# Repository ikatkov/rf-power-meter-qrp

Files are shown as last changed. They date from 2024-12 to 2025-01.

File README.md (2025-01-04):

# RF Power Meter QRP

This microcontroller-based RF power meter is tailored for Ham QRP, capable of measuring up to 6W. It offers power readings in two formats:

1. Milliwatts (mW) – displayed as a 4-digit value without decimals.
1. Decibel-milliwatts (dBm) – shown with one decimal place. Since the display lacks a dot, the reading appears as a 3-digit number (e.g., "123" represents 12.3 dBm).
1. Accuracy 0.4% @ 6W (+-25mW), 5% @ 10mW (+-0.5mW)

## Features

- Up to 6W RF power meter, assumes sin wave
- Peak power hold mode
- Compensated frequency resonse, less that 1.03 SWR 2-50MHz
- Power measurements in dBm and Watts on 4-digit LED display
- Support for multiple Ham frequency bands (3.7-50MHz)
- Calibrated and uses polynomial curve fitting for accurate measurements. Manually set frequency band in settings.
- Battery voltage monitoring and auto power-off after 5 minutes of inactivity. Press any button to reset.
- Vent holes on plastic enclosure have filters made of surgical mask fiber (anti dust for field operation)

## 2MHz - 50MHz
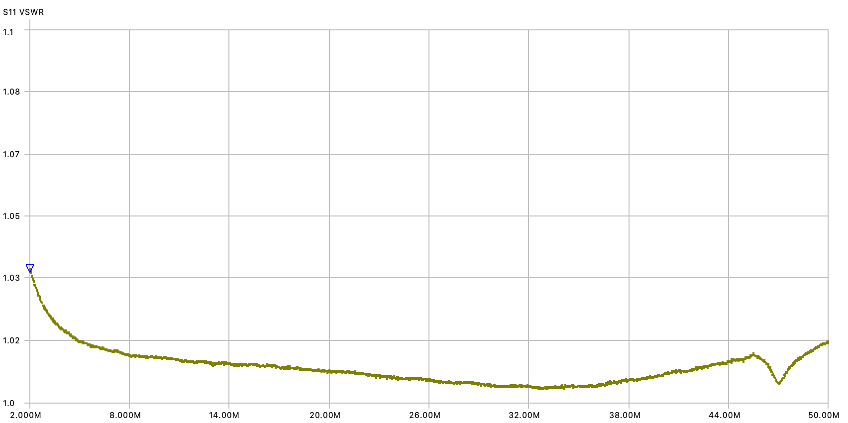
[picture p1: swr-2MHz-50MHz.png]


## 2MHz - 175MHz
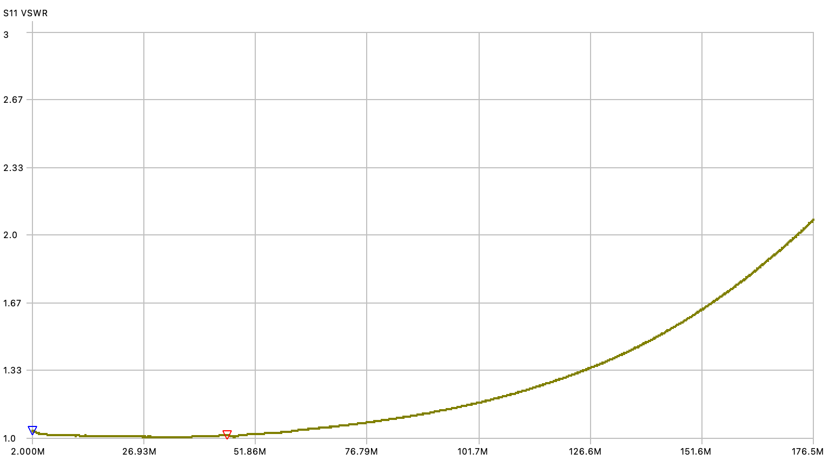
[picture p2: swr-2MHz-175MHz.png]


## Hardware

Schematic - [PDF](schematic.pdf)

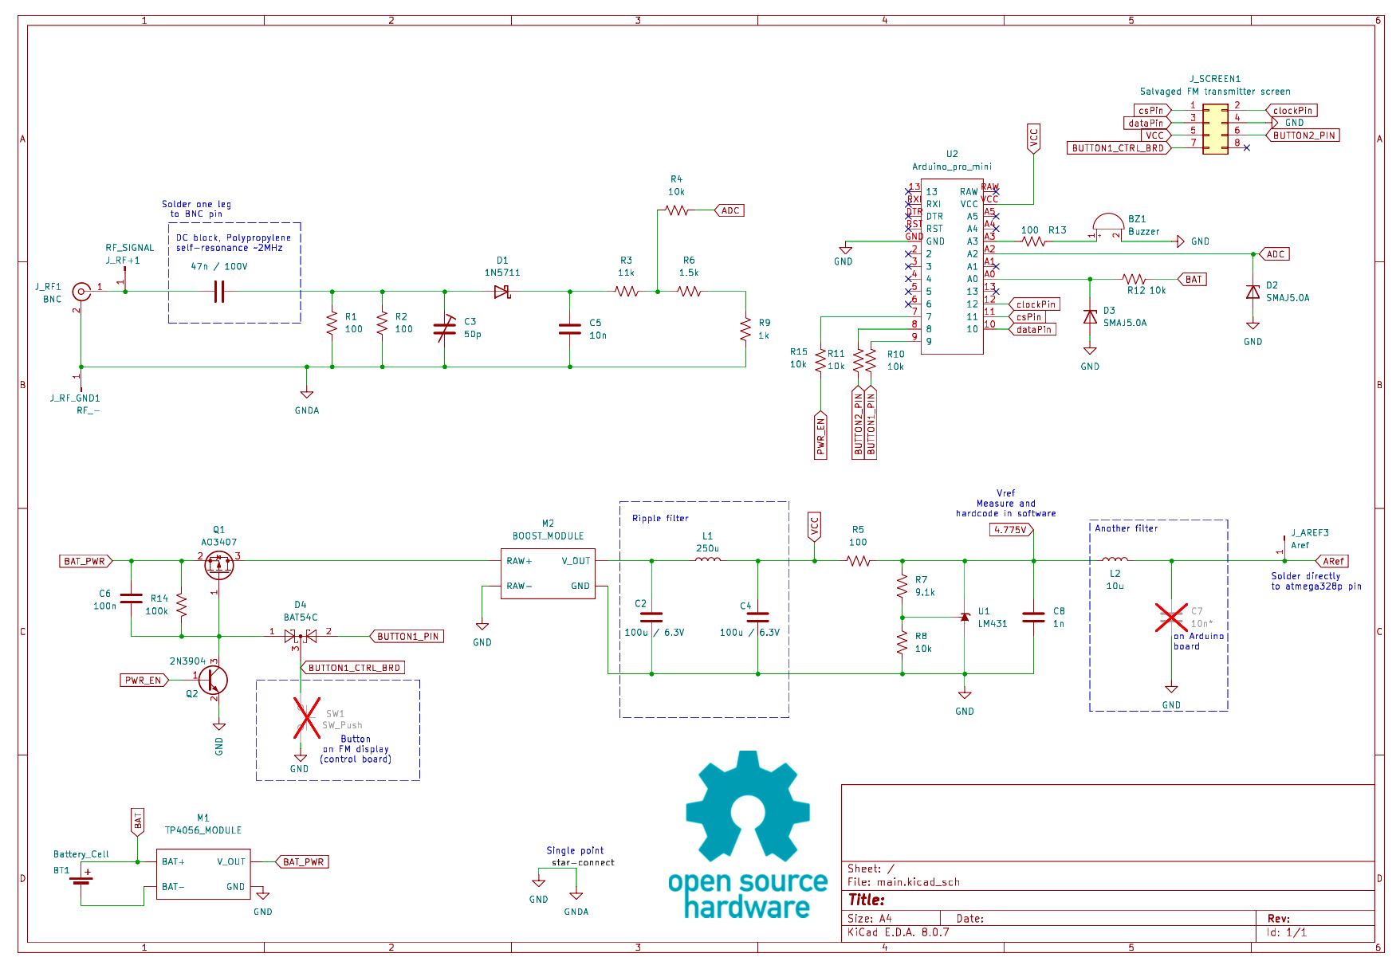
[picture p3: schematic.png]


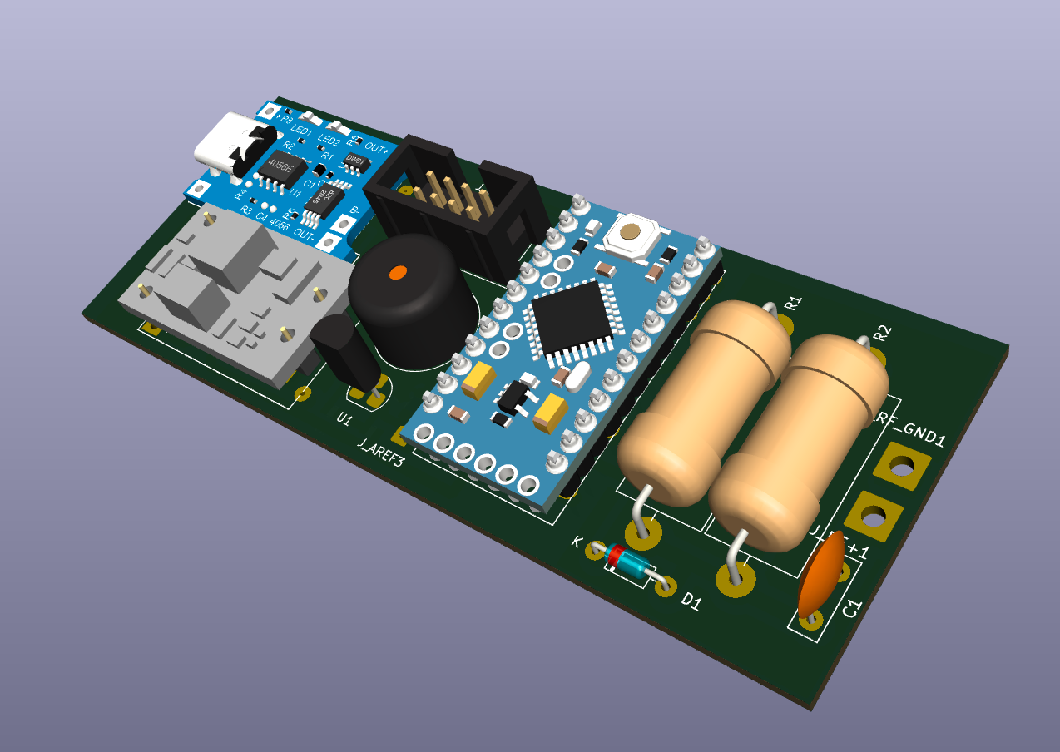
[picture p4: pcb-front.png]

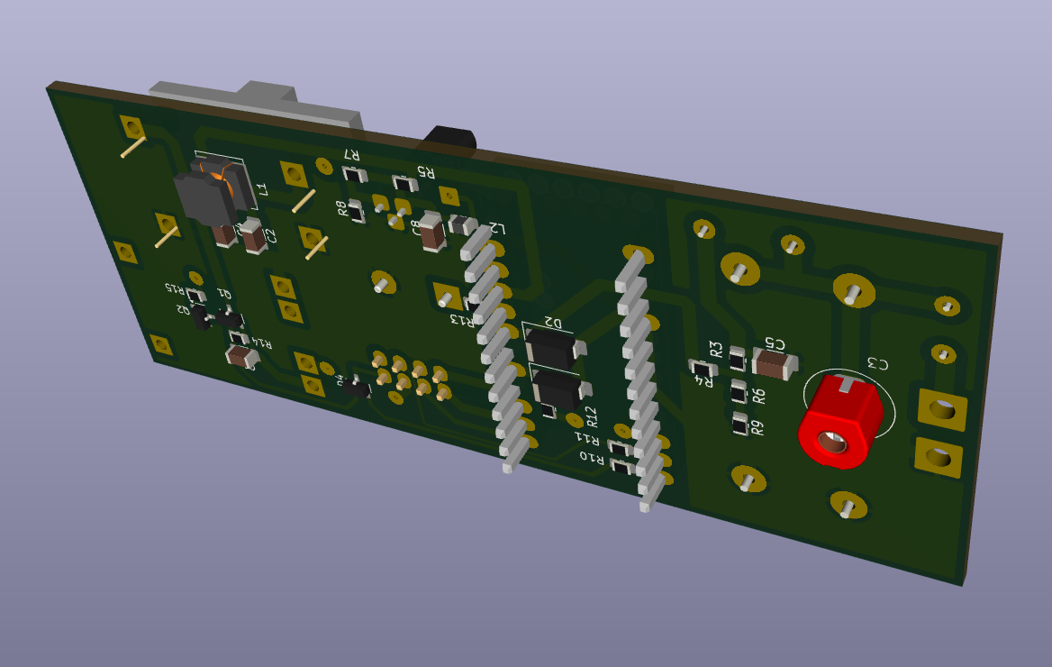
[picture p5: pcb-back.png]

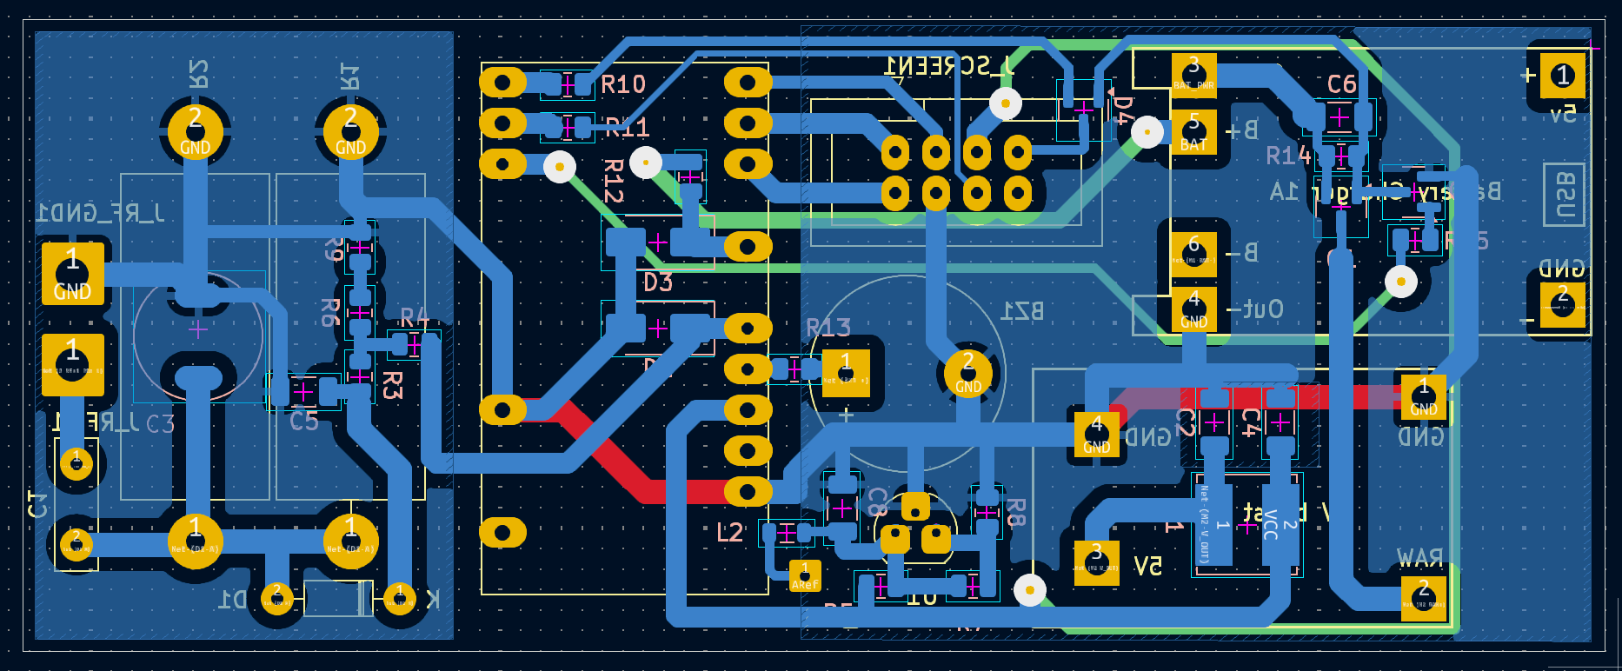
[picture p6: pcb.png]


- Arduino-compatible microcontroller
- 4-digit+MHz symbol LED display (salavged from a car FM transmitter)
- RF didode detector circuit
- Power latch circuit for MCU driven turn off
- Buzzer for audio feedback
- External precision voltage reference 

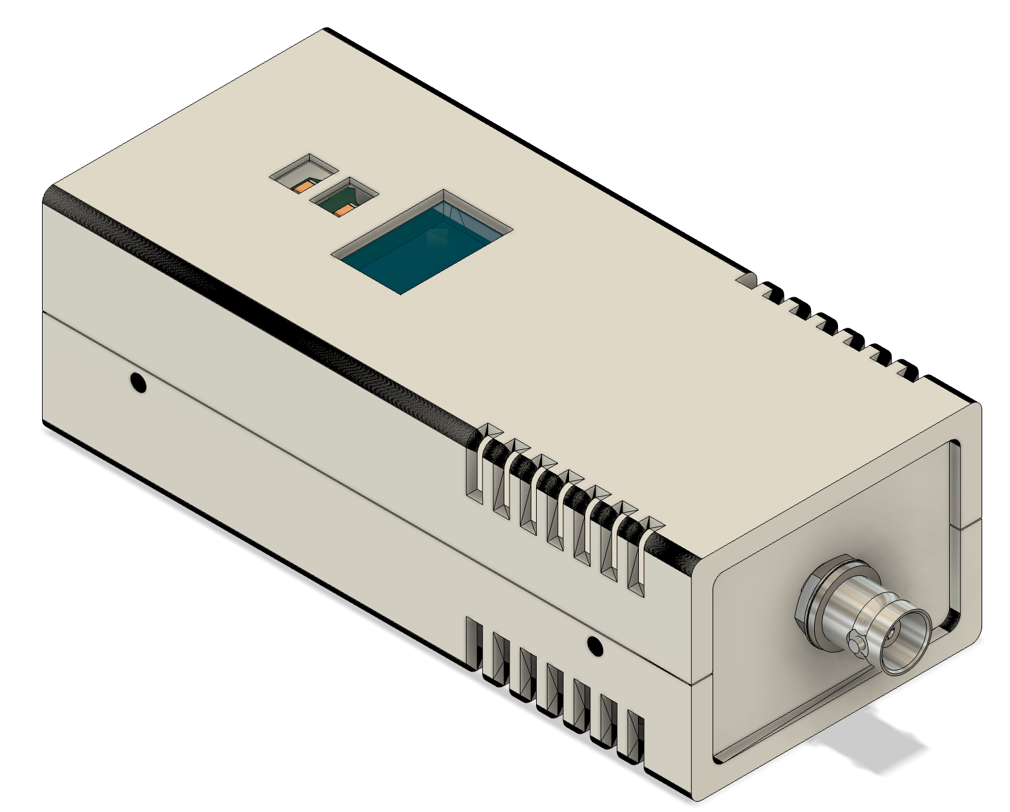
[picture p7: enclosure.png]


## Usage

- **To Power On**: Flip the main (storage mode) switch to ON. Press and hold the OK button (lower) to power on. Device starts with battery voltage displayed, followed by the currently selected frequency band. 

- **Info Button** (top):
  - Single click: Toggle between dBm/Watts
  - Double click: Enter measurement mode selection. Use the same button to switch between modes **continious** (default) vs **hold peak** mode. Use OK button to confirm when done.
  - Long press: Enter frequency band selection. Use the same button to cycle through bands.Use OK button to confirm when done.
- **OK Button** (bottom):
  - Single click: When in main screen - resets to zero, in menu screens confirms selection and exit to the main screen.
  - Long press (2s): Powers off

## Technical Specifications

- Calibrated for Ham frequency bands: 3.7MHz, 7.2MHz, 14.2MHz, 18MHz, 21MHz, 24MHz, 28MHz, 50MHz 
- Accuracy 0.4% @ 6W (+-25mW), 5% @ 10mW (+-0.5mW)
- Min power level: 2mW (3dBm)
- Max power level: 6.3W (38dBm) in short burst, 4W continious
- Not temperature compensated
- Internal 500mAh battery, USB charged
- When powered off, 200uA current consumption. You can use storage mode switch to disconnect internal battery competely.

## Notes

Since it's a diode detector the only thing it can measure is peak voltage. Code inside assumes that input RF signal is a pure sine wave to make RF power calculations. 

### Frequency compensation

Leads and connector and other stray inductance skew 50Ω impedance, one good way to compensate is to add adjustanble shunt capacitance. Use VNA to adjust after pcb assembly.

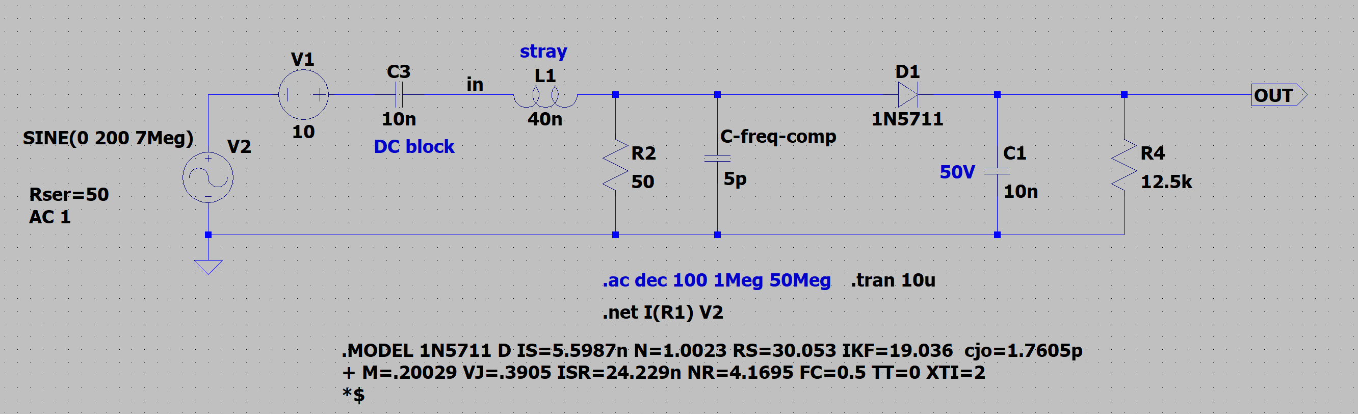
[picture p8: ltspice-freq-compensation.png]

[ltspice file](ltspice/qrt-rf-power-meter-shunt-cap-compensation.asc)

### DC supply filtering

Internal battery is nominal 3.7V, but the salvaged LCD screen needs 5V. There is boost DC-DC converter that gives 200mV ripple. There are two filters - one right after the converter, this goes to MCU. There is another one just before reference voltage goes to Aref pin.

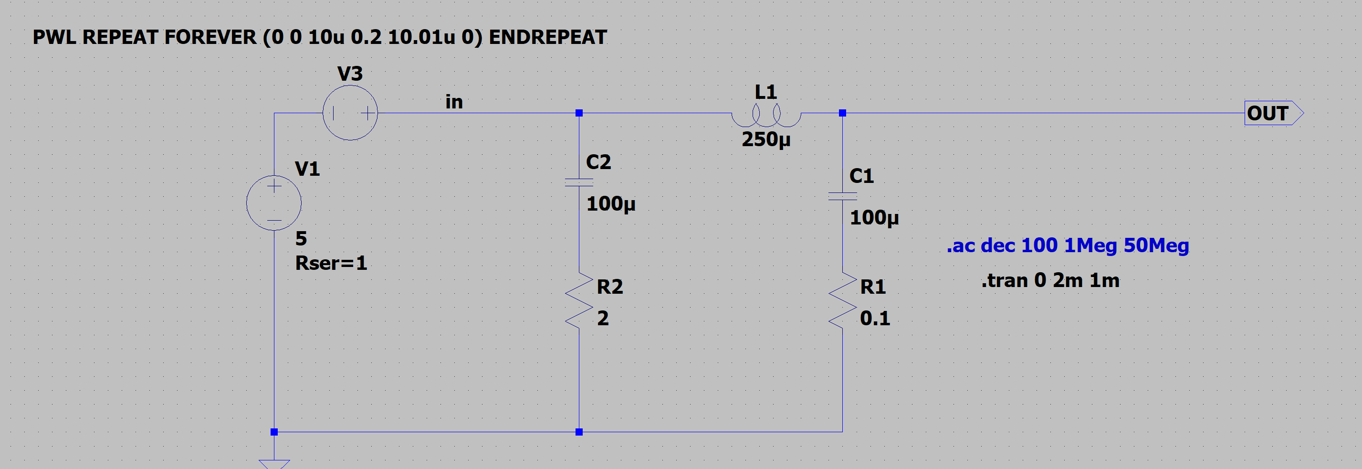
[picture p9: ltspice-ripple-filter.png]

[ltspice file](ltspice/power-ripple-filter.asc)

### Interface

The Salvaged FM LCD screen has two buttons, so I had to fallback to "click" vs "double-click" vs "long click" technique. The same button function differently depending in which mode device currently is - "main screen" vs "settings"

The screen itself has 4 digits and one dot. The dot is connected to "MHz" symbol. They always lit together.
Although I needed the dot for measurements, for example for dBms, I decided that showing "12.3 MHz" and claiming that this is "12.3 dBm" is rather akward. So the reading appears as a 3-digit number e.g. "123" represents 12.3 dBm. Watts reading always appear as 4 digit numbers with leading zeros as mW, "0123" reading represents 123mW. The dot and the "MHz" symbol come very handy when displaying frequency band. This setting is used to select which callibration curve to apply to the actual measurement.

Here is transition diagram:

```
                 ┌───────────────┐                   ┌─────────────┐
                 │ Cycle through ├───OK─button───────►  Saves to   │
                 │   Ham bands   │    click          │    NVRAM    │
                 └──────▲────────┘                   └───────┬─────┘
                        │                                    │      
                   info button                               │      
                     click                                   │      
                        │                                    │      
                 ┌──────┴────────┐                           │      
                 │Frequency band │                           │      
                 │  selection    │                           │      
                 │   screen      │                           │      
                 └───────────────┘                           │      
                       ▲ ▲                                   │      
                       │ │                                   │      
                       │ │                                   │      
                    info button                              │      
        ┌───────────long press─────────┐                     │      
        │                              │                     │      
        │                              │                     │      
        │                              │                     │      
┌───────┴───────┐              ┌───────┴───────┐             │      
│  Main screen  ├─info─button─►│  Main screen  │◄────────────┘      
│    mWatts     │◄──click──────┤     dBm       │◄────────────┐      
└───────┬───────┘              └───────┬───────┘             │      
        │                              │                     │      
        │                              │                     │      
        │                              │                     │      
        └──────────info button─────────┘                     │      
                   double│click                              │      
                      │  │                                   │      
                ┌─────▼──▼─────┐         When in the         │      
                │  Continious  │        "Hold Peak mode"     │      
                │     vs       │         display blinks      │      
                │  Hold peak   │                             │      
                └───────┬──────┘                             │      
                        │                                    │      
                   info button                               │      
                     click                                   │      
                        │                                    │      
                ┌───────▼─────────┐                          │      
                │  Cycle through  ├────OK─button─────────────┘      
                │    two modes    │     click                       
                └─────────────────┘                                                                                  
```                   

In any mode, long press on the "OK" button turns power off.

## License

[MIT License](LICENSE)

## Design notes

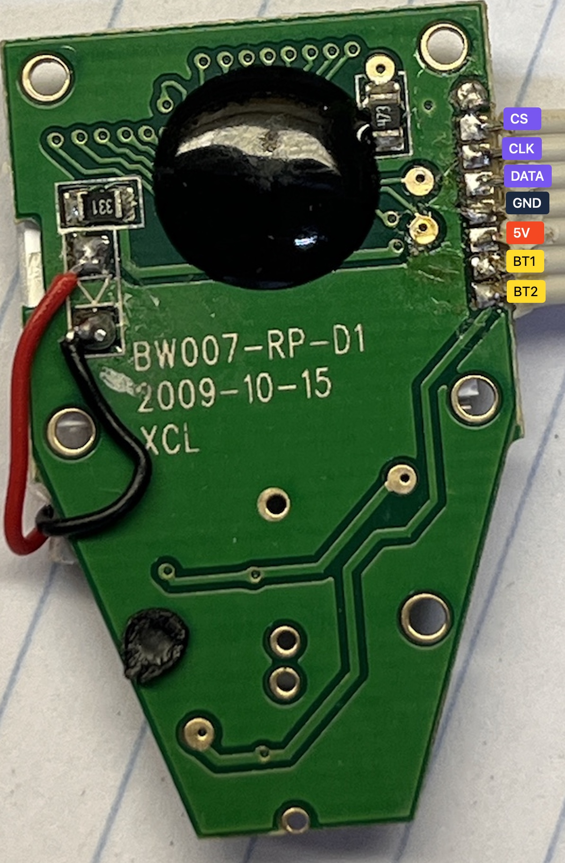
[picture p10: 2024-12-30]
pinout.jpg

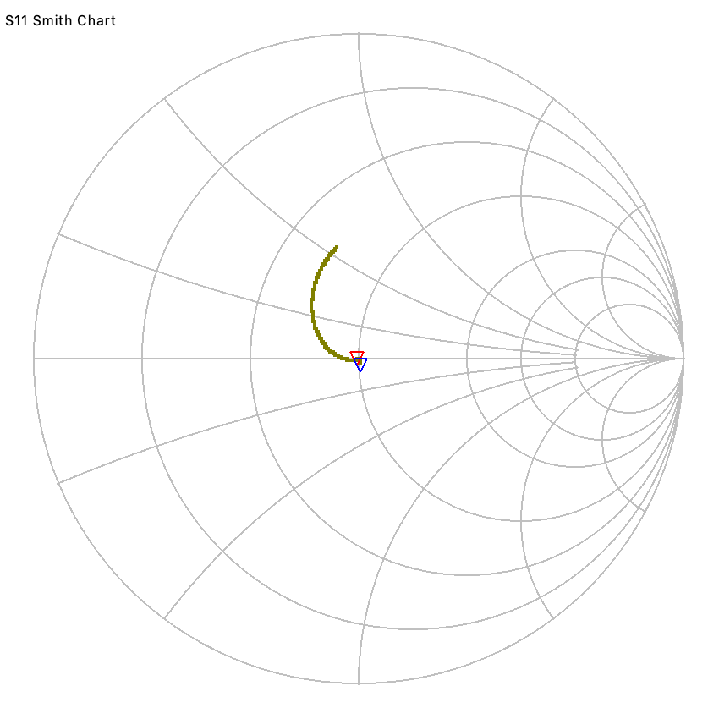
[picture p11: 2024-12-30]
smith-2MHz-175MHz.png

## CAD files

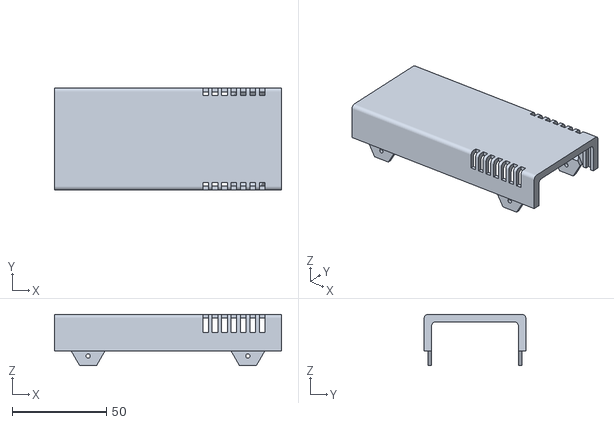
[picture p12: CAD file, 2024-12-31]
Box-top.stl
120.6 x 54.0 x 27.1

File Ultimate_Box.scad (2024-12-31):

/* Box design originally by:
////////////////////////////////////////////////////////////////////
              -    FB Aka Heartman/Hearty 2016     -
              -   http://heartygfx.blogspot.com    -
              -       OpenScad Parametric Box      -
              -         CC BY-NC 3.0 License       -
////////////////////////////////////////////////////////////////////

Improved by jbebel:
http://github.com/jbebel/Ultimate-Box-Maker

To create a box, start by modifying the numerical parameters in the sections
below. This can be accomplished using a release of OpenSCAD newer than 2015.03.
As of the time of writing, this means that a development snapshot is required.
The Thingiverse Customizer may also potentially work, but at the time of
writing, it was inoperable.

The simplest choice is to hand-edit the .scad file. Feature toggles are
annotated with a comment. The other numerical parameters are measurements in
mm. Everything is parametrized, so if you double all the non-feature parameters
you will double the box size in every dimension. Certain parameters are derived
from other parameters. If you wish to override them, you may, but sensible
defaults have been chosen. Notably the design in this revision is particularly
PCB-centric, in that you should start with your PCB size and adjust the margins
around it to determine the box size. If you care more about the box size, you
can set the Length, Width, and Height explicitly, but read the comments around
them.

Once your box is sized appropriately, you can use the Panel modules to design
the holes and text for the front and back panels. Helper variables are provided
to assist you in positioning these holes relative to the PCB, if your holes are
for PCB-mounted components.

When you are ready to print, adjust the values in the "STL element to export"
section, and export each part one at a time.

Experimental options are provided for a screwless design, but these are
untested. In particular, the box fixation tabs may need thicknesses adjusted
in order to have the appropriate flexibility.
*/

// preview[view:north east, tilt:top diagonal]
//----------------------- Box parameters ---------------------------

/* [Box options] */
// - Wall thickness
Thick = 2;
// - Panel thickness
PanelThick = 2;
// - Font Thickness
FontThick = 0.5;
// - Filet Radius
Filet = 2;
// - 0 for beveled, 1 for rounded
Round = 1; // [0:No, 1:Yes]
// - Printer margin around interior cutouts
CutoutMargin = 0.3;
// - Margin between mating parts
PartMargin = 0.1;
// - PCB feet? (x4)
PCBFeet = 1; // [0:No, 1:Yes]
// - Decorations?
Decorations = 1; // [0:No, 1:Yes]
// - Decorations to ventilation holes
Vent = 1; // [0:No, 1:Yes]
// - Decoration-Holes width (in mm)
Vent_width = 3;
// - Tolerance (Panel/rails gap on one edge)
PanelThickGap = CutoutMargin + PartMargin;
PanelVerticalGap = PartMargin;
PanelHorizontalGap = CutoutMargin + PartMargin;


/* [Box Fixation Tabs] */
// - Side screw hole (or snap) diameter
ScrewHole = 2.2606;
// - Screw thread major diameter for outer shell
BoxHole = 2.8448;
// Thickness of fixation tabs
TabThick = 2;
// Back left tab
BLTab = 1; // [0:Bottom, 1:Top]
// Back right tab
BRTab = 1; // [0:Bottom, 1:Top]
// Front left tab
FLTab = 1; // [0:Bottom, 1:Top]
// Front right tab
FRTab = 1; // [0:Bottom, 1:Top]
// EXPERIMENTAL: Snap tabs
SnapTabs = 0; // [0:Screws, 1:Snaps]


/* [PCB options] */
// - PCB Length
PCBLength = 109;
// - PCB Width
PCBWidth = 40;
// - PCB Thickness
PCBThick = 1.6;
// You likely need to maintain |TabThick| margin on the left and right for tabs
// and whatnot.
// - Margin between front panel and PCB
FrontEdgeMargin = 1;
// - Margin between back panel and PCB
BackEdgeMargin = 1;
// - Margin between left wall and PCB
LeftEdgeMargin = 5;
// - Margin between right wall and PCB
RightEdgeMargin = 5;
// - Margin between top of PCB and box top.
TopMargin = 25;


/* [PCB_Feet] */
// - Foot height above box interior
FootHeight = 8;
// - Foot diameter
FootDia = 8;
// - Hole diameter, or peg for screwless design
FootHole = 0; // tap size for #4 coarse-thread
// - EXPERIMENTAL Screwless design
Screwless = 0; // [0:Screws, 1:Screwless]
FootFilet = 0;

// Foot centers are specified as distance from PCB back-left corner.
// X is along the "length" axis, and Y is along the "width" axis.
// - Foot 1 distance from back PCB edge
Foot1X = 4;
// - Foot 1 distance from left PCB edge
Foot1Y = 13;
// - Foot 2 distance from back PCB edge
Foot2X = 4;
// - Foot 2 distance from right PCB edge
Foot2YFromEdge = 25;
Foot2Y = PCBWidth - Foot2YFromEdge;

// - Foot 3 distance from front PCB edge
Foot3XFromEdge = 12;
Foot3X = PCBLength - Foot3XFromEdge;
// - Foot 3 distance from left PCB edge
Foot3Y = 3;

// - Foot 4 distance from front PCB edge
Foot4XFromEdge = 11;
Foot4X = PCBLength - Foot4XFromEdge;
// - Foot 4 distance from right PCB edge
Foot4YFromEdge = 4;
Foot4Y = PCBWidth - Foot4YFromEdge;


/* [STL element to export] */
// - Top shell
TShell = 0; // [0:No, 1:Yes]
// - Bottom shell
BShell = 0; // [0:No, 1:Yes]
// - Front panel
FPanL = 1; // [0:No, 1:Yes]
// - Back panel
BPanL = 0; // [0:No, 1:Yes]
// - Panel holes and text
PanelFeatures = 0; // [0:No, 1:Yes]


/* [Hidden] */
// - feet color
color_feet = "Red";

// - Shell color
Couleur1 = "Orange";
// - Panel color
Couleur2 = "OrangeRed";
// - Text color
TextColor = "White";
// - making decorations thicker if it is a vent to make sure they go through
// shell
// Add a small number to Thick in case Filet is 0.
Dec_Thick = Vent ? Thick*1.001 + Filet : Thick/2;
// Separate vents with a square pillar by default.
Dec_Spacing = Thick + Vent_width;
// X offset to center of first vent
Dec_Offset = Thick*2 + PanelThick + PanelThickGap*2 + Dec_Spacing - Vent_width/2;

// Resolution based on Round parameter. Set this first number to something
// smaller to speed up processing. It should always be a multiple of 4.
Resolution = Round ? 100: 4;

/* Calculate box dimensions from PCB. If you want a more box-centric design
   where the outer diameter of the box matters more than the margins around
   the PCB you can set these manually. The PCB will still be placedaccording
   to the left and back margins, and if you want to use the screwless box
   design, you will need to set the TopMargin to
   (Height - Thick*2 - FootHeight - PCBThick)
*/
Length = PCBLength + FrontEdgeMargin + BackEdgeMargin + ((Thick + PanelThick + PanelThickGap*2)*2);
Width = PCBWidth + LeftEdgeMargin + RightEdgeMargin + Thick*2;
Height = FootHeight + PCBThick + TopMargin + Thick*2;
echo("Box: ", Length=Length, Width=Width, Height=Height);
// X position inset of mounting holes and tabs
MountInset = Thick*3 + PanelThick + PanelThickGap*2 + ScrewHole*4;

// Calculate panel dimensions from box dimensions.
PanelWidth = Width - Thick*2 - PanelHorizontalGap*2;
PanelHeight = Height - Thick*2 - PanelVerticalGap*2;


/*  Panel Manager

    Use the below 4 modules to produce holes and text on the front and back
    panels. The holes modules should contain instances of SquareHole or
    CylinderHole defined later in this file. The text modules should contain
    instances of LText or CText defined later in this file. It is
    recommended to use variables that you define for your needs to create
    the size and positions of these objects.
*/

// Calculate board-relative positions with respect to the panel, for
// convenience in placing panel elements.
TopOfBoardWRTPanel = FootHeight + PCBThick - PanelVerticalGap;
LeftEdgeOfBoardWRTFPanel = LeftEdgeMargin - PanelHorizontalGap;
LeftEdgeOfBoardWRTBPanel = RightEdgeMargin - PanelHorizontalGap;
// Visible panel edges
PanelBottomEdge = Thick - PanelVerticalGap;
PanelTopEdge = PanelHeight - Thick + PanelVerticalGap;
PanelLeftEdge = Thick - PanelHorizontalGap;
PanelRightEdge = PanelWidth - Thick + PanelHorizontalGap;


// Holes for front panel
module FPanelHoles() {
    // SquareHole(On/Off, Xpos,Ypos,Length,Width,Filet)
    SquareHole(1, 20, 20, 15, 10, 1);
    SquareHole(1, 40, 20, 15, 10, 1);
    SquareHole(1, 60, 20, 15, 10, 1);
    // CylinderHole(On/Off, Xpos, Ypos, Diameter)
    CylinderHole(1, 27, 40, 8);
    CylinderHole(1, 47, 40, 8);
    CylinderHole(1, 67, 40, 8);
    SquareHole(1, 20, 50, 80, 30, 3);
    CylinderHole(1, 93, 30, 10);
    SquareHole(1, 120, 20, 30, 60, 3);
}


// Text for front panel
module FPanelText() {
    // LText(On/Off, Xpos, Ypos, "Font", Size, "Text", "HAlign", "VAlign")
    LText(1, 20, 83, "Arial Black", 4, "Digital Screen", HAlign="left");
    LText(1, 120, 83, "Arial Black", 4, "Level", HAlign="left");
    LText(1, 20, 11, "Arial Black", 6, "  1     2      3", HAlign="left");
    // CText(On/Off, Xpos, Ypos, "Font", Size, Diameter, Arc(Deg), Starting Angle(Deg),"Text")
    CText(1, 93, 29, "Arial Black", 4, 10, 180, 0,
          ["1", "." , "3", "." , "5", "." , "7", "." , "9", "." , "11"]);
}
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

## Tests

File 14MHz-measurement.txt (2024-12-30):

| true Vpp | calculated, mW | measured, mW |
| --- | --- | --- |
| 2.4 | 14.4 | 14 |
| 4.64 | 53.82 | 52 |
| 8.6 | 184.9 | 166 |
| 16 | 640 | 561 |
| 20.3 | 1030 | 904 |
| 27.4 | 1877 | 1611 |
| 35.9 | 3222 | 2774 |
| 44.2 | 4884 | 4176 |
| 50.6 | 6401 | 5373 |

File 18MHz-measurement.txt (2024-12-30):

| true Vpp | calculated, mW | measured, mW |
| --- | --- | --- |
| 2.8 | 19.6 | 18 |
| 5.46 | 74.53 | 67 |
| 17.2 | 739.6 | 645 |
| 23.9 | 1428 | 1258 |
| 33 | 2723 | 2257 |
| 41.3 | 4264 | 3497 |
| 50.8 | 6452 | 5265 |

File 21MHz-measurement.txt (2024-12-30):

| true Vpp | calculated, mW | measured, mW |
| --- | --- | --- |
| 2.85 | 20.31 | 18 |
| 5.6 | 78.4 | 67 |
| 17.6 | 774.4 | 641 |
| 25.2 | 1588 | 1220 |
| 33.6 | 2822 | 2165 |
| 41.8 | 4368 | 3325 |
| 51.5 | 6631 | 4949 |

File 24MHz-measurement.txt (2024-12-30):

| true Vpp | calculated, mW | measured, mW |
| --- | --- | --- |
| 2.8 | 19.6 | 18 |
| 5.5 | 75.63 | 66 |
| 17.2 | 739.6 | 633 |
| 24.8 | 1538 | 1229 |
| 33.4 | 2789 | 2203 |
| 41.4 | 4285 | 3420 |
| 50.4 | 6350 | 5171 |

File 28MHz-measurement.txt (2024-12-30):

| true Vpp | calculated, mW | measured, mW |
| --- | --- | --- |
| 2.8 | 19.6 | 18 |
| 5.5 | 75.63 | 63 |
| 17.2 | 739.6 | 604 |
| 25.2 | 1588 | 1174 |
| 33.9 | 2873 | 2097 |
| 42.2 | 4452 | 3259 |
| 52.2 | 6812 | 4880 |

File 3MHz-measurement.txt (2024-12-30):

| true Vpp | calculated, mW | measured, mW |
| --- | --- | --- |
| 2.4 | 14.4 | 14 |
| 5 | 62.5 | 60 |
| 8.6 | 184 | 185 |
| 20 | 1000 | 914 |
| 23.6 | 1392 | 1305 |
| 32.2 | 2592 | 2367 |
| 40.1 | 4020 | 3693 |
| 49.5 | 6126 | 5579 |

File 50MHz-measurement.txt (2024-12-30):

| true Vpp | calculated, mW | measured, mW |
| --- | --- | --- |
| 3 | 22.5 | 23 |
| 6.3 | 99.22 | 81 |
| 15.3 | 585.2 | 472 |
| 20 | 1000 | 785 |
| 23.5 | 1381 | 1123 |
| 34.6 | 2993 | 2000 |
| 43.3 | 4687 | 3093 |
| 53 | 7022 | 4654 |

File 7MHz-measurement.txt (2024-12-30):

| true Vpp | calculated, mW | measured, mW |
| --- | --- | --- |
| 2.4 | 14.4 | 14 |
| 5 | 62.5 | 60 |
| 8.6 | 184 | 192 |
| 19.6 | 960.4 | 880 |
| 23.2 | 1346 | 1241 |
| 26.6 | 1769 | 1559 |
| 31.7 | 2512 | 2249 |
| 43.1 | 4644 | 4144 |
| 52.7 | 6943 | 6091 |

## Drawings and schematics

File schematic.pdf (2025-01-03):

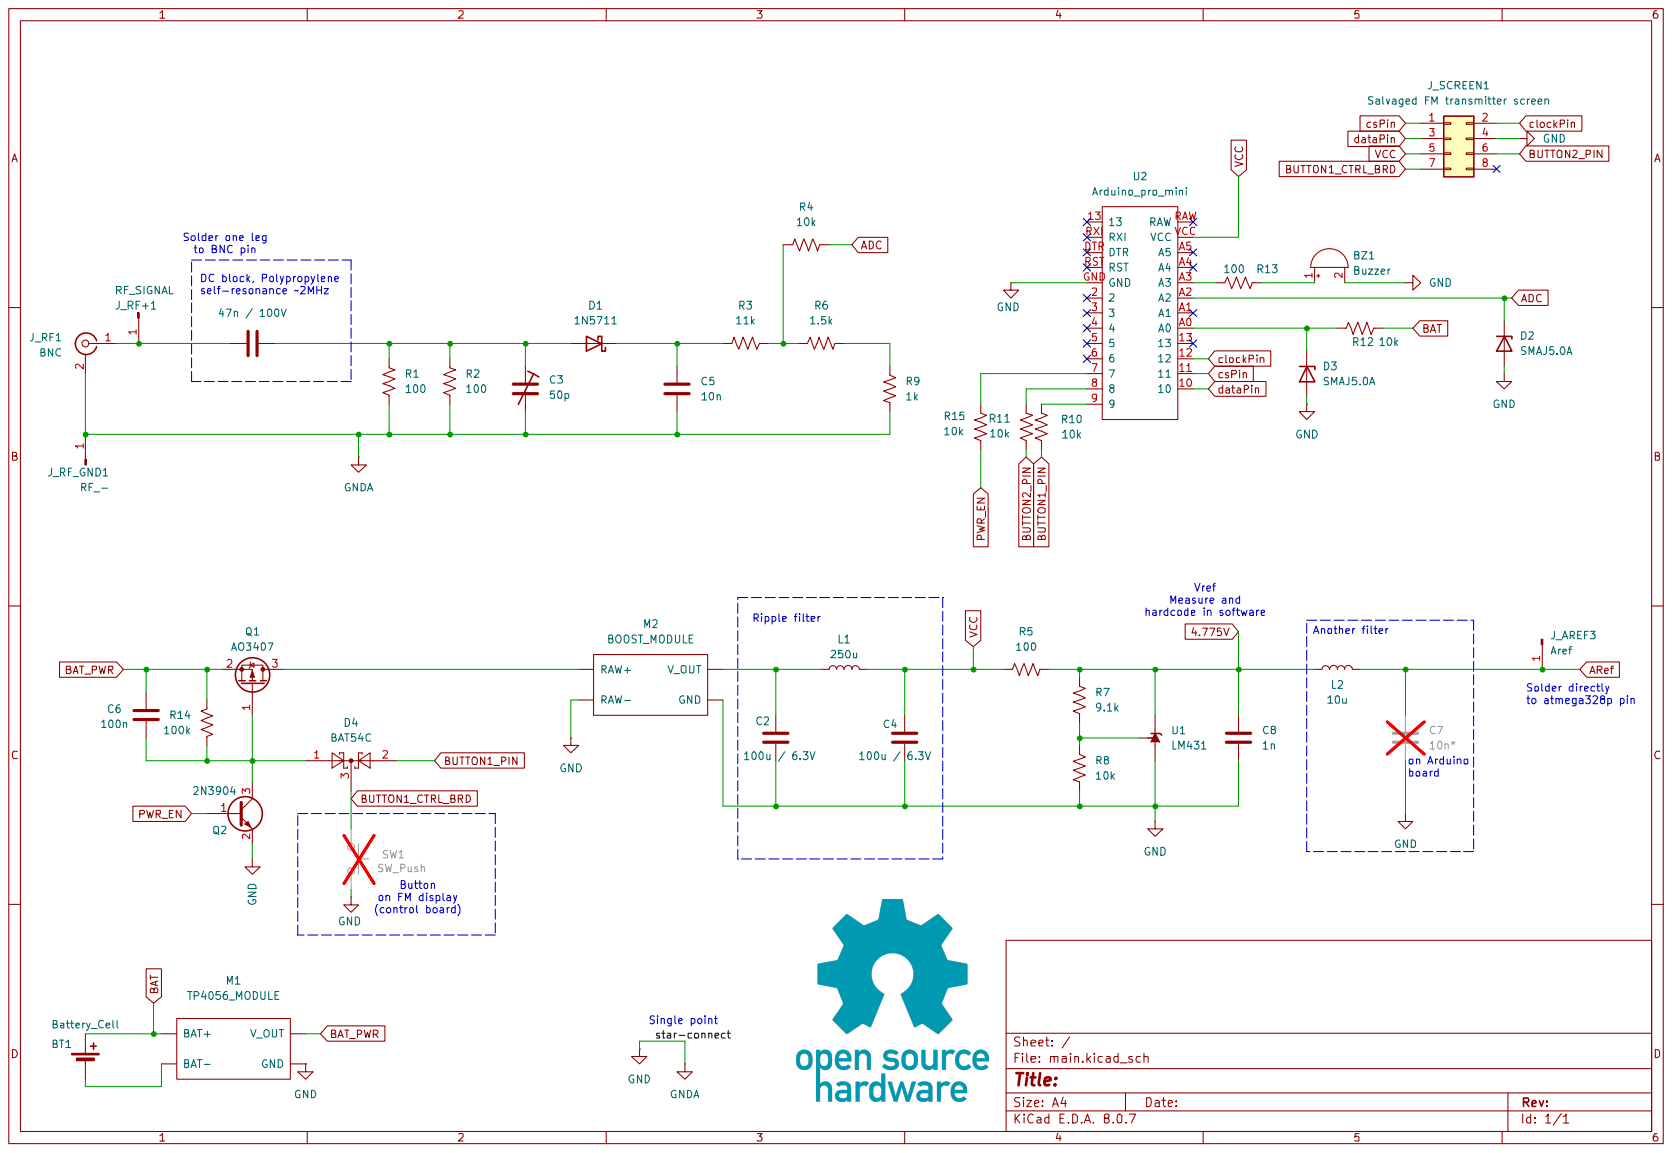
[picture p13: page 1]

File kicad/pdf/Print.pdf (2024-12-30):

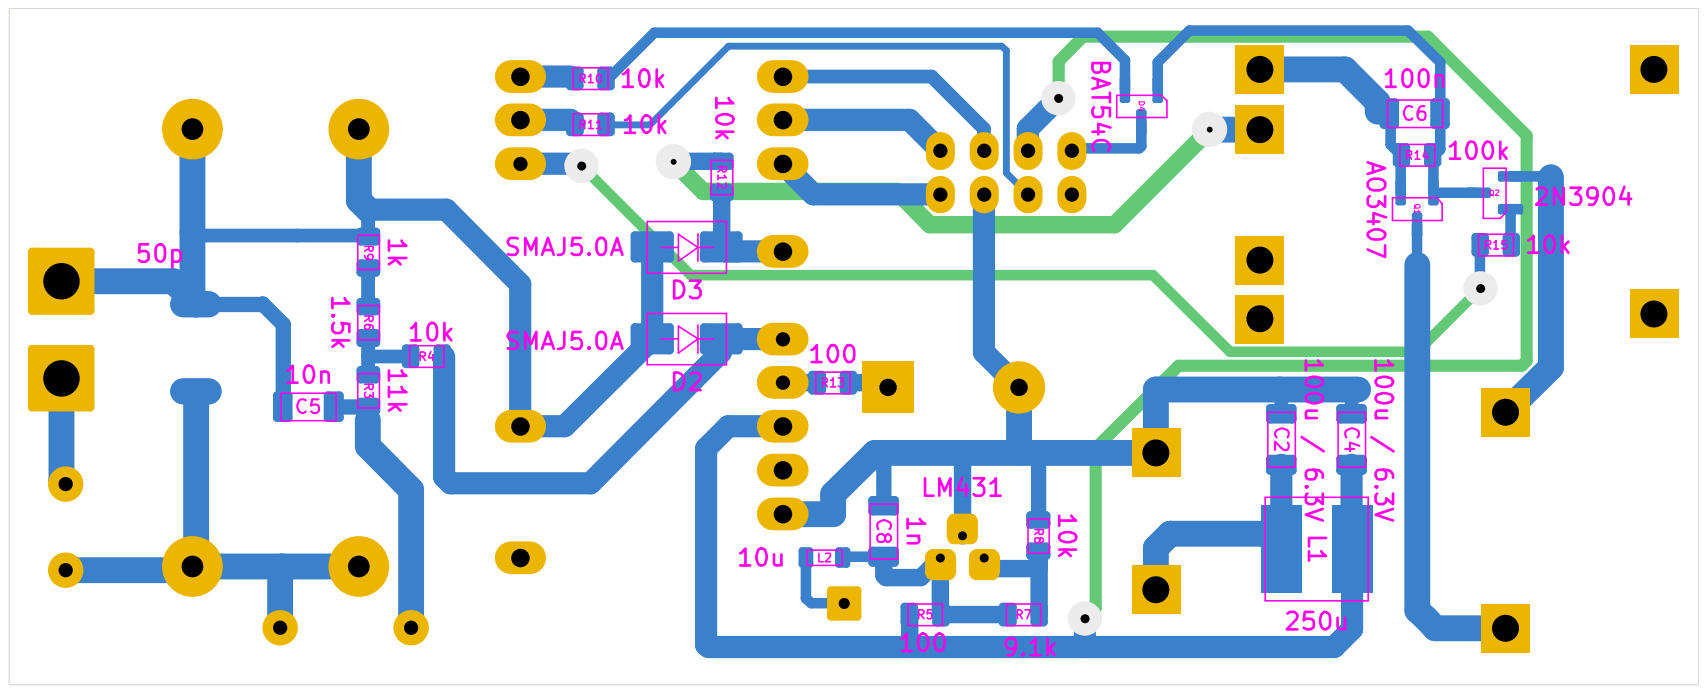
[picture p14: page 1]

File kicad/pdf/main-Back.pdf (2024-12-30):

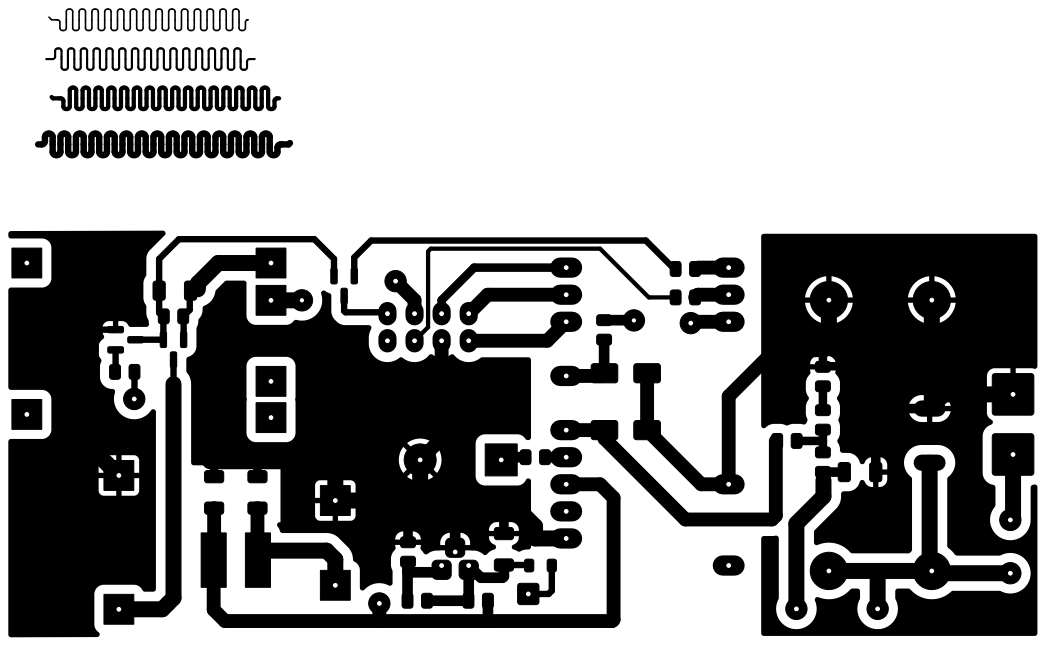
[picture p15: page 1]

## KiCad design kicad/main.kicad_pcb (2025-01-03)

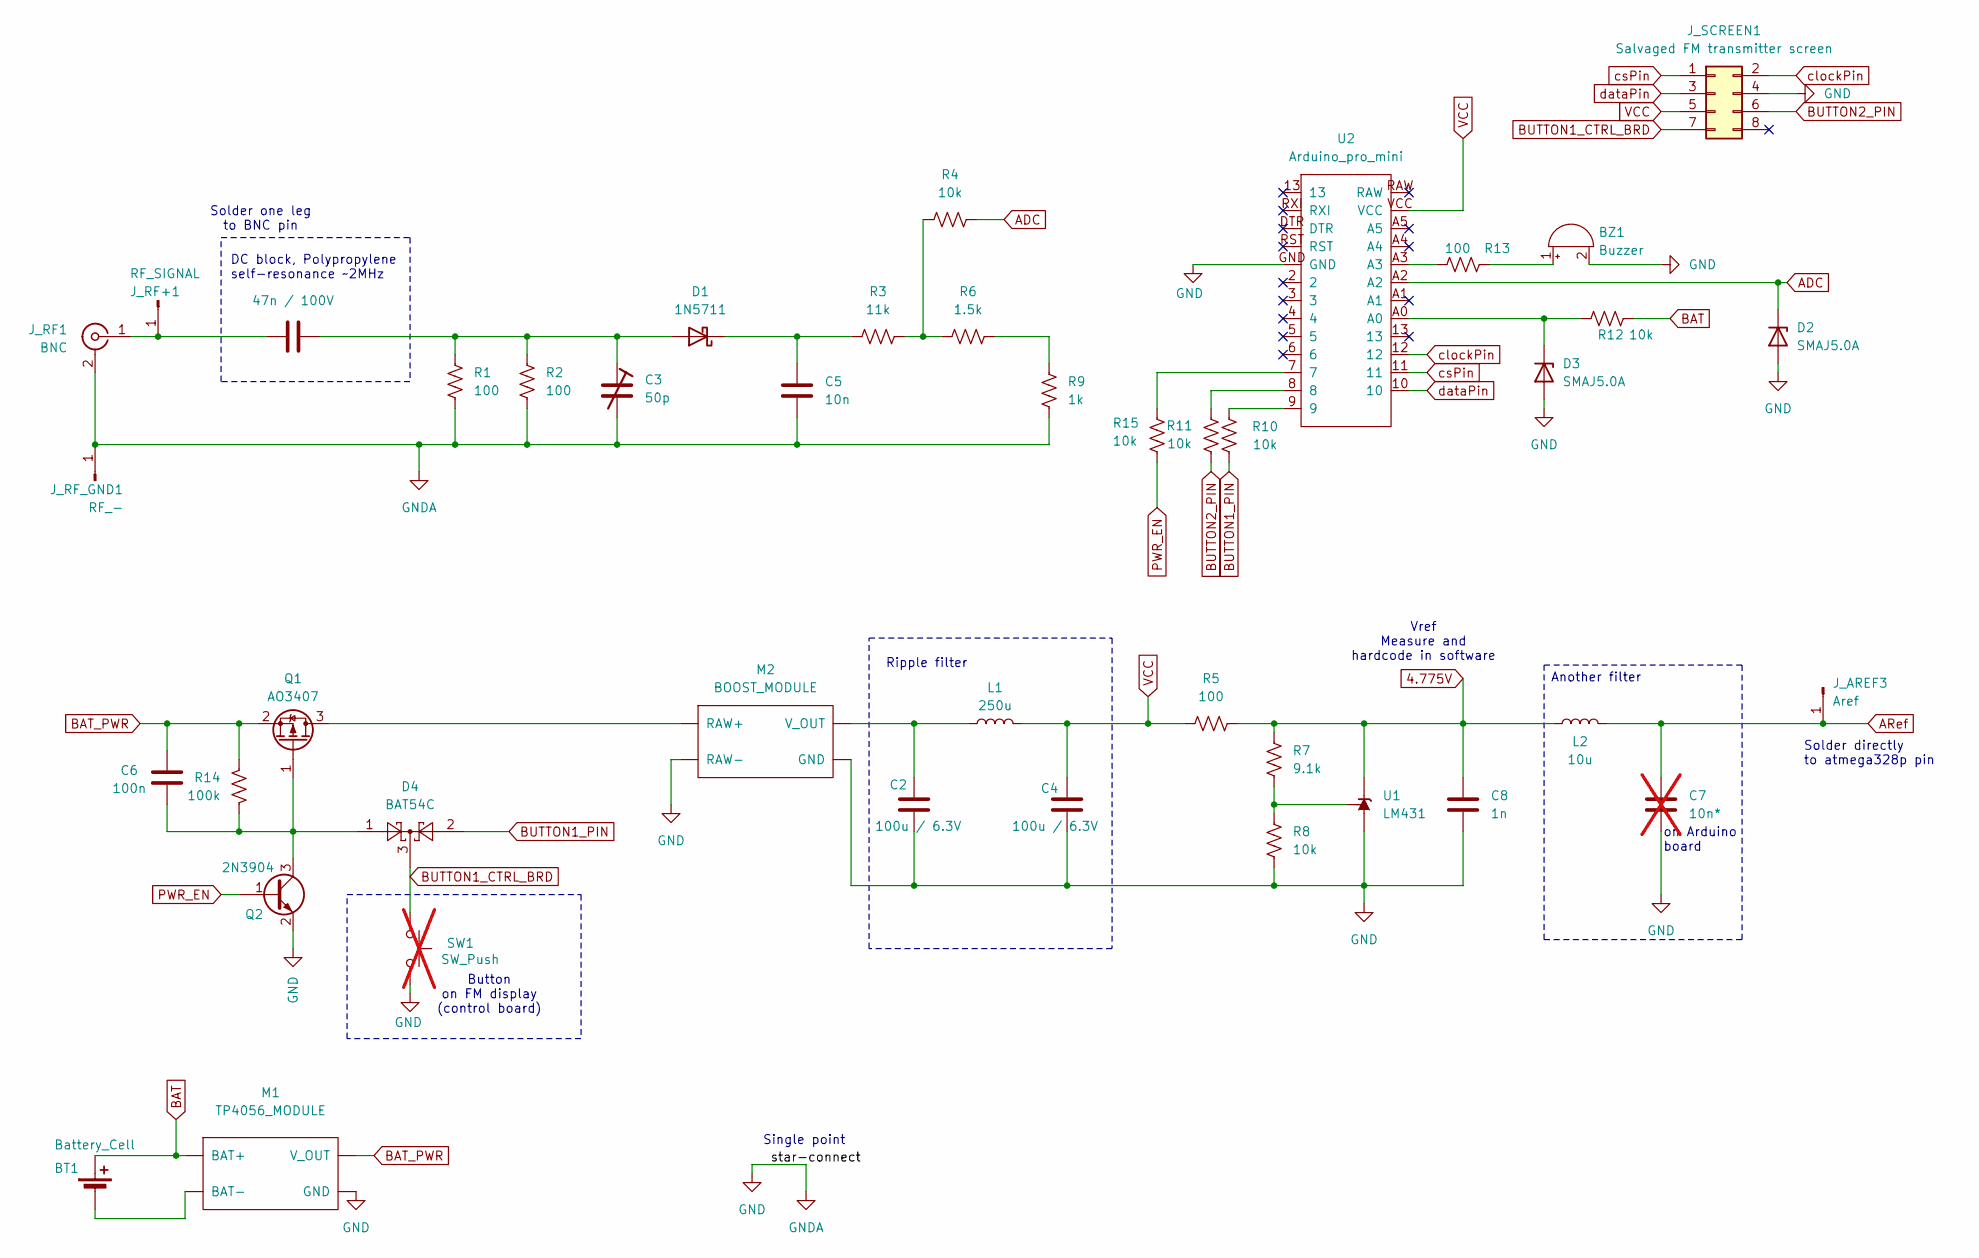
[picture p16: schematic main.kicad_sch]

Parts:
BT1: Battery_Cell
BZ1: Buzzer; Buzzer_12x9.5RM7.6
C1: 47n / 100V; C_Disc_D8.0mm_W2.5mm_P5.00mm
C2, C4: 100u / 6.3V; C_1206_3216Metric
C3: 50p; trimmer-capacitor-JML06
C5: 10n; C_1206_3216Metric
C6: 100n; C_1206_3216Metric
C7: 10n*; C_1206_3216Metric; not fitted
C8: 1n; C_1206_3216Metric
D1: 1N5711; D_DO-35_SOD27_P7.62mm_Horizontal
D2, D3: SMAJ5.0A; D_SMA
D4: BAT54C; SOT-23
J_AREF3: Aref; SolderWire-0.25sqmm_1x01_D0.65mm_OD2mm
J_RF1: BNC; SolderWire-1.5sqmm_1x01_D1.7mm_OD3.9mm
J_RF+1: RF_SIGNAL; SolderWire-1.5sqmm_1x01_D1.7mm_OD3.9mm
J_RF_GND1: RF_-; SolderWire-1.5sqmm_1x01_D1.7mm_OD3.9mm
J_SCREEN1: Salvaged FM transmitter screen; IDC-Header_2x04_P2.54mm_Vertical
L1: 250u; L_Bourns_SRN6045TA
L2: 10u; L_0805_2012Metric
M1: TP4056_MODULE; TP4056-18650
M2: BOOST_MODULE; boost-module
Q1: AO3407; SOT-23
Q2: 2N3904; SOT-23
R1, R2: 100; R_Axial_DIN0922_L20.0mm_D9.0mm_P25.40mm_Horizontal
R3: 11k; R_0805_2012Metric
R4, R8, R10, R11, R12, R15: 10k; R_0805_2012Metric
R5, R13: 100; R_0805_2012Metric
R6: 1.5k; R_0805_2012Metric
R7: 9.1k; R_0805_2012Metric
R9: 1k; R_0805_2012Metric
R14: 100k; R_0805_2012Metric
SW1: SW_Push; SW_Tactile_SPST_Angled_PTS645Vx31-2LFS; not fitted
U1: LM431; TO-92L_HandSolder
U2: Arduino_pro_mini; ARDUINO_PRO_MINI_NO_A5

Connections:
4.775V: C8.1, L2.1, R5.1, R7.1, U1.3 (K)
ADC: D2.1 (K), R4.2, U2.A2
ARef: C7.1, J_AREF3.1, L2.2
BAT: BT1.1 (+), M1.5 (BAT+), R12.1
BAT_PWR: C6.2, M1.3 (V_OUT), Q1.2 (S), R14.2
BUTTON1: D4.2, R10.2
BUTTON1_PIN: D4.3, J_SCREEN1.7, SW1.1
BUTTON2: J_SCREEN1.6, R11.2
GND: BZ1.2 (-), C2.2, C3.2, C4.2, C5.2, C7.2, C8.2, D2.2 (A), D3.2 (A), J_RF1.2 (Ext), J_RF_GND1.1, J_SCREEN1.4, M1.4 (GND), M2.1 (RAW-), M2.4 (GND), Q2.2 (E), R1.2, R2.2, R8.2, R9.2, SW1.2, U1.2 (A), U2.GND
unnamed: BZ1.1 (+), R13.1
unnamed: C1.2, C3.1, D1.2 (A), R1.1, R2.1
unnamed: C5.1, D1.1 (K), R3.1
unnamed: D3.1 (K), R12.2, U2.A0
unnamed: C1.1, J_RF1.1 (In), J_RF+1.1
unnamed: BT1.2 (-), M1.6 (BAT-)
unnamed: M2.2 (RAW+), Q1.3 (D)
unnamed: C2.1, L1.1, M2.3 (V_OUT)
unnamed: C6.1, D4.1, Q1.1 (G), Q2.3 (C), R14.1
unnamed: R3.2, R4.1, R6.2
unnamed: R6.1, R9.1
unnamed: R10.1, U2.9
unnamed: R11.1, U2.8
unnamed: R13.2, U2.A3
unnamed: R15.2, U2.7
unnamed: R7.2, R8.1, U1.1 (REF)
PWR_EN: Q2.1 (B), R15.1
VCC: C4.1, J_SCREEN1.5, L1.2, R5.2, U2.VCC
clockPin: J_SCREEN1.2, U2.12
csPin: J_SCREEN1.1, U2.11
dataPin: J_SCREEN1.3, U2.10

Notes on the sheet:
Ripple filter
Vref Measure and hardcode in software
Another filter
DC block, Polypropylene self-resonance ~2MHz
Button on FM display (control board)
Solder one leg to BNC pin
Single point
on Arduino board
Solder directly to atmega328p pin

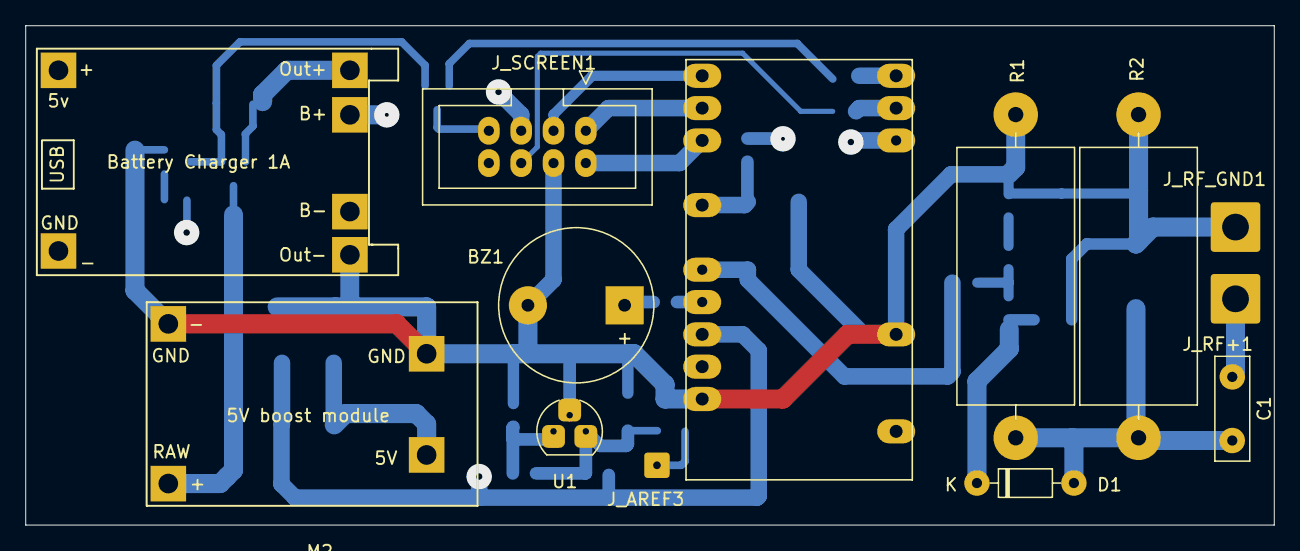
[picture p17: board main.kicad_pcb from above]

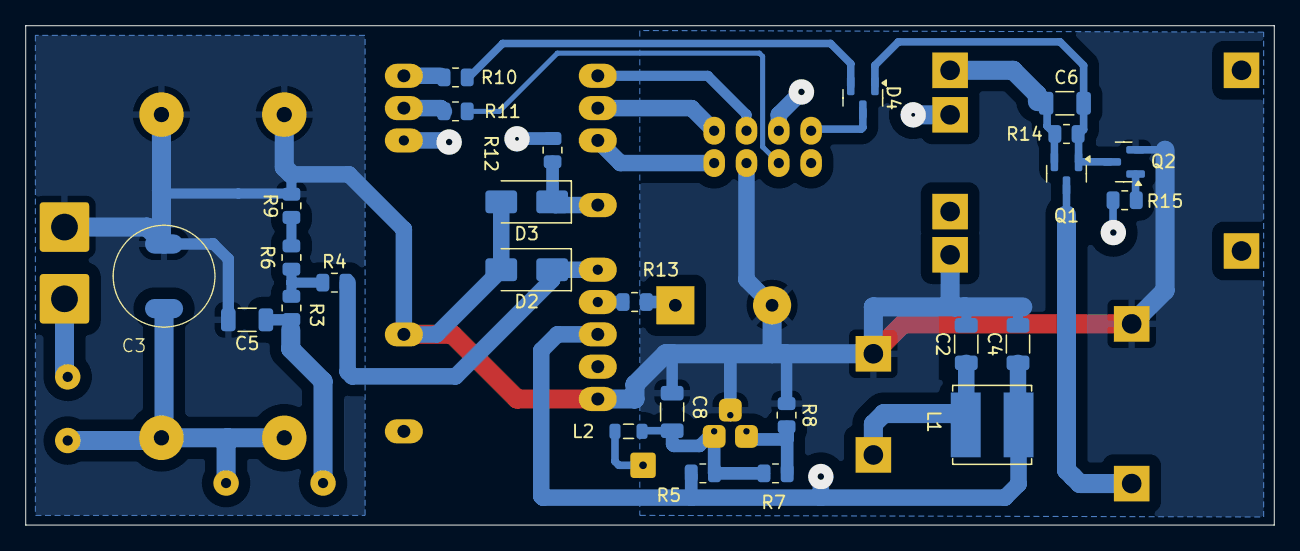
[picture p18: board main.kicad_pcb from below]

Board: 4 copper layers, 98.1 x 39.2 mm, 39 parts (26 on the bottom side), 29 nets.

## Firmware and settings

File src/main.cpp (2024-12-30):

#include "FmDisplay.h"
#include <TimerOne.h>
#include <OneButton.h>
#include <EEPROM.h>
#include "main.h"

#define DEBUG

const int CS_PIN = 11;
const int CLOCK_PIN = 12;
const int DATA_PIN = 10;

const int BUTTON_MENU_PIN = 8;
const int BUTTON_OK_PIN = 9;

const int POWER_LATCH_PIN = 7;

const int BUZZER_PIN = A3;
const int RF_PEAK_PIN = A2;
const int BATTERY_PIN = A0;

const float rf_voltage_divider_r1 = 11.0;     // 11k resistor
const float rf_voltage_divider_r2 = 2.5;      // 2.5k
const float REFERENCE_VOLTAGE = 4.762;        // measured reference voltage
const float DIODE_VOLTAGE_DROP = 0.42;        // TODO: apply curve fitting to get the actual value
const float ADC_CORRECTION = 0.1988 / 0.1930; // measured real voltage on ADC

const int TEXT_DBM[] = {_space, _d, _b, _space};
const int TEXT_PO[] = {_U, _a, _t, _t};
const int TEXT_FREQUENCY[] = {_F, _r, _E, _q};
const int TEXT_HOLD[] = {_H, _o, _1, _d};
const int TEXT_CONT[] = {_C, _o, _n, _t};
const int TEXT_BATTTERY[] = {_b, _a, _t, _t};
const int TEXT_OVERLOAD[] = {_8, _8, _8, _8};

const int TEXT_SAVE_ANIMATION1[] = {_space, segment_g, _space, _space};
const int TEXT_SAVE_ANIMATION2[] = {_space, segment_c, _space, _space};
const int TEXT_SAVE_ANIMATION3[] = {_space, segment_d, _space, _space};
const int TEXT_SAVE_ANIMATION4[] = {_space, segment_e, _space, _space};

const int TEXT_ZEROING_ANIMATION1[] = {_0, _dash, _dash, _dash};
const int TEXT_ZEROING_ANIMATION2[] = {_0, _0, _dash, _dash};
const int TEXT_ZEROING_ANIMATION3[] = {_0, _0, _0, _dash};
const int TEXT_ZEROING_ANIMATION4[] = {_0, _0, _0, _0};
const int TEXT_ZEROING_ANIMATION5[] = {_space, _0, _0, _0};
const int TEXT_ZEROING_ANIMATION6[] = {_space, _space, _0, _0};
const int TEXT_ZEROING_ANIMATION7[] = {_space, _space, _space, _0};

const int TEXT_BLANK[4] = {_space, _space, _space, _space};

const unsigned long COUNTDOWN_DELAY = 300000; // 5 minutes
const unsigned long SHUTDOWN_DELAY = 320000;  // 5 minutes 20 seconds

volatile bool displayOn = true;
volatile double rf_power_mw = 0;
volatile double rf_power_dbm = 0;

int display_measurement_number = 0;
uint16_t rf_adc_value = 0;
uint16_t old_rf_adc_value = 0;

unsigned long button_press_time;
bool turnoff_countdown;

enum MEASUREMENT_UNITS
{
    W,
    DBM
};
enum MEASUREMENT_MODE
{
    CONTINIOUS,
    HOLD_PEAK
};

// 3.7MHz, 7.2MHz, 14.2MHz, 18MHz, 21MHz, 24MHz, 28MHz, 50MHz
const uint16_t available_frequency_bands[8] = {37, 72, 142, 180, 211, 249, 280, 500};
uint8_t frequency_band = 1; // 7.2MHz

const double fitting_function_coefficient[8][6] = {
    {2.0245749998638694e-15, -2.3699472615230126e-11, 9.070791422764846e-08, -0.00012760316726548302, 1.142113933556968, -8.307120539266869},   // 3MHz
    {-2.832639856233634e-15, 4.008791152785013e-11, -1.9347494506898958e-07, 0.0003762711505537496, 0.8649979956416018, 5.7510956015560994},    // 7.2MHz
    {-7.810853772218834e-16, 1.1557752449794416e-11, -5.7078681287238685e-08, 0.00011412767037503853, 1.0842364385975602, -0.4732162724031951}, // 14.2MHz
    {7.630398035762764e-15, -8.768622813420562e-11, 3.289916470982582e-07, -0.0004330479624294447, 1.3214604701574173, -7.765773398063638},     // 18MHz
    {-9.175671545215191e-15, 1.0720650694796922e-10, -4.32168272385996e-07, 0.0007161423096984246, 0.8881486345114411, 9.449364406775501},      // 21MHz
    {-4.63099664245735e-15, 5.860488098036351e-11, -2.638794351628782e-07, 0.0004933640336449699, 0.9393501818574546, 6.66894491307017},        // 24MHz
    {-9.804873517894107e-15, 1.173642971202226e-10, -4.897181239269411e-07, 0.0008448732362330482, 0.8542679565355191, 10.664231398894488},     // 28MHz
    {4.1232168516747e-14, -4.1479653503906627e-10, 1.350228380965077e-06, -0.0015175248806550679, 1.8014116551731685, -28.51094013300302}       // 50MHz
};

enum STATE
{
    MAIN,
    MEASUREMENT_MODE_SELECT,
    FREQUENCY_SELECT
};

STATE state = STATE::MAIN;

MEASUREMENT_UNITS measurement_units = MEASUREMENT_UNITS::W;
MEASUREMENT_MODE measurement_mode = MEASUREMENT_MODE::CONTINIOUS;

FmDisplay fmDisplay = FmDisplay(CLOCK_PIN, DATA_PIN, CS_PIN);

OneButton button_OK(BUTTON_OK_PIN, true);
OneButton button_MENU(BUTTON_MENU_PIN, true);

// Function to compute the correction
double compute_correction(const double measured, const double coefficients[6])
{
    return coefficients[0] * pow(measured, 5) +
           coefficients[1] * pow(measured, 4) +
           coefficients[2] * pow(measured, 3) +
           coefficients[3] * pow(measured, 2) +
           coefficients[4] * measured +
           coefficients[5];
}

void render_display();

void overload_tone()
{
    tone(BUZZER_PIN, 1700, 1000);
}

void startup_tone()
{
    tone(BUZZER_PIN, 1000, 200);
    delay(200);
    tone(BUZZER_PIN, 1500, 600);
}

void shutdown_tone()
{
    tone(BUZZER_PIN, 1500, 200);
    delay(200);
    tone(BUZZER_PIN, 1000, 600);
    delay(600);
}

void button_press_tone()
{
    tone(BUZZER_PIN, 1200, 200);
}

void int_to_symbols(uint16_t number, int digits[4], const bool leading_spaces = measurement_units == MEASUREMENT_UNITS::DBM)
{
    digits[0] = number / 1000; // Thousands place
    number %= 1000;            // Remaining number after thousands

    digits[1] = number / 100; // Hundreds place
    number %= 100;            // Remaining number after hundreds

    digits[2] = number / 10; // Tens place
    digits[3] = number % 10; // Ones place
    for (byte i = 0; i < 3; i++)
    {
        if (digits[i] == 0 && leading_spaces)
            digits[i] = 10;
        else
            break;
    }

    for (uint8_t i = 0; i < 4; i++)
    {
        digits[i] = symbols[digits[i]];
    }
}

void display_slideout_animation()
{
    int symbols[4];
    int_to_symbols(display_measurement_number, symbols);
    for (int i = 3; i >= 0; i--)
    {
        fmDisplay.display_symbols(symbols);
        delay(100);
        // move the digits to the left
        for (int j = 0; j < 3; j++)
        {
            symbols[j] = symbols[j + 1];
            if (j >= i)
            {
                symbols[j] = _space;
            }
        }
        symbols[3] = _space;
    }
}

void debug_print_symbols(const int symbols[4], const int display_text[4])
{
    Serial.print("Symbols: [");
    for (int k = 0; k < 4; k++)
    {
        Serial.print(symbols[k]);
        Serial.print(" ");
    }
    Serial.print("]\t[");
    for (int k = 0; k < 4; k++)
    {
        Serial.print(display_text[k]);
        Serial.print(" ");
    }
    Serial.println("]");
}

void display_scroll_animation(const int *scroll_text, int length)
{
    int symbols[4] = {_space, _space, _space, _space};

    for (int i = 0; i < length - 3; i++)
    {
        for (int j = 0; j < 4; j++)
        {
            if (i + j < length)
            {
                symbols[j] = scroll_text[i + j];
            }
            else
            {
                symbols[j] = _space;
            }
        }
        fmDisplay.display_symbols(symbols);
        delay(100);
    }
}

void display_save_animation()
{
    Timer1.detachInterrupt();
    fmDisplay.display_show_dot(false);

    const int *animations[] = {TEXT_SAVE_ANIMATION1, TEXT_SAVE_ANIMATION2, TEXT_SAVE_ANIMATION3, TEXT_SAVE_ANIMATION4};
    for (int i = 0; i < 8; ++i)
    {
        fmDisplay.display_symbols(animations[i % 4]);
        delay(100);
    }

    Timer1.attachInterrupt(render_display);
}

void display_zeroing_animation()
{
    Timer1.detachInterrupt();
    fmDisplay.display_show_dot(false);

    const int *animations[] = {TEXT_ZEROING_ANIMATION1, TEXT_ZEROING_ANIMATION2, TEXT_ZEROING_ANIMATION3, TEXT_ZEROING_ANIMATION4, TEXT_ZEROING_ANIMATION5, TEXT_ZEROING_ANIMATION6, TEXT_ZEROING_ANIMATION7};
    for (int i = 0; i < 7; ++i)
    {
        fmDisplay.display_symbols(animations[i]);
        delay(100);
    }

    Timer1.attachInterrupt(render_display);
}

void display_battery_voltage()
{
    int batteryVoltage = analogRead(BATTERY_PIN);
    Serial.print("Battery voltage ADC: ");
    Serial.print(batteryVoltage);
    float voltage = float(batteryVoltage + 0.5) * REFERENCE_VOLTAGE / 1024;
    Serial.print("\tBattery voltage: ");
    Serial.println(voltage);

    int symbols[4];
    int text_to_scroll[16];

    int_to_symbols(voltage * 1000, symbols);
    memcpy(text_to_scroll, TEXT_BLANK, sizeof(TEXT_BLANK));
    memcpy(text_to_scroll + 4, TEXT_BATTTERY, sizeof(TEXT_BATTTERY));
    memcpy(text_to_scroll + 8, TEXT_BLANK, sizeof(TEXT_BLANK));
    memcpy(text_to_scroll + 12, symbols, sizeof(symbols));
    display_scroll_animation(text_to_scroll, sizeof(text_to_scroll) / sizeof(text_to_scroll[0]));
}

void display_frequency_band()
{
    fmDisplay.display_show_dot(true);
    fmDisplay.display_int(available_frequency_bands[frequency_band], true);
}

void read_rf_power()
{
    rf_adc_value = analogRead(RF_PEAK_PIN);
    if (measurement_mode == MEASUREMENT_MODE::HOLD_PEAK && rf_adc_value < old_rf_adc_value)
    {
        return;
    }
    old_rf_adc_value = rf_adc_value;

    if (rf_adc_value == 0)
    {
        rf_power_dbm = 0;
        rf_power_mw = 0;
    }
    else
    {
#ifdef DEBUG
        Serial.print("RF power ADC: ");
        Serial.print(rf_adc_value);
#endif

        double rf_voltage = ADC_CORRECTION * rf_adc_value * REFERENCE_VOLTAGE / 1023.0;
#ifdef DEBUG
        // Serial.print("\t RF power @ADC, V: ");
        // Serial.print(rf_voltage, 4);
#endif
        rf_voltage = rf_voltage * (rf_voltage_divider_r1 + rf_voltage_divider_r2) / rf_voltage_divider_r2;
#ifdef DEBUG
        // Serial.print("\t RF power before divider, V: ");
        // Serial.print(rf_voltage, 4);
#endif

        rf_voltage = DIODE_VOLTAGE_DROP + rf_voltage;
#ifdef DEBUG
        Serial.print("\t RF power, Vp: ");
        Serial.print(rf_voltage, 4);
        Serial.print("\t RF power, Vpp: ");
        Serial.print(2 * rf_voltage, 4);
#endif

        double rf_voltage_rms = rf_voltage / sqrt(2);
#ifdef DEBUG
        Serial.print("\t RF power, Vrms: ");
        Serial.print(rf_voltage_rms, 4);
#endif
        rf_power_mw = rf_voltage_rms * rf_voltage_rms * 100.0 / 5;

#ifdef DEBUG
        Serial.print("\t RF power, mW: ");
        Serial.print(rf_power_mw, 4);
#endif

        rf_power_mw = compute_correction(rf_power_mw, fitting_function_coefficient[frequency_band]);

#ifdef DEBUG
        Serial.print("\t Corrected RF power, mW: ");
        Serial.print(rf_power_mw, 4);
#endif

        rf_power_dbm = 10 * log10(rf_power_mw) * 10;
#ifdef DEBUG
        Serial.print("\t RF power dBm: ");
        Serial.print(rf_power_dbm, 4);
        Serial.println("");
#endif
    }
    if (measurement_units == MEASUREMENT_UNITS::DBM)
    {
        display_measurement_number = round(rf_power_dbm);
    }
    else if (measurement_units == MEASUREMENT_UNITS::W)
    {
        display_measurement_number = round(rf_power_mw);
    }
    if (rf_adc_value >= 1022)
    {
        overload_tone();
    }
}

void render_display()
{
    // Serial.println("render_display, state:");

    // switch (state)
    // {
    // case STATE::MAIN:
    //     Serial.println("MAIN");
    //     break;
    // case STATE::MEASUREMENT_MODE_SELECT:
    //     Serial.println("MEASUREMENT_MODE_SELECT");
    //     break;
    // case STATE::FREQUENCY_SELECT:
    //     Serial.println("FREQUENCY_SELECT");
    //     break;
    // default:
    //     Serial.println("UNKNOWN");
    //     break;
    // }

    if (state == STATE::MAIN)
    {
        fmDisplay.display_show_dot(false);
        if (measurement_mode == MEASUREMENT_MODE::HOLD_PEAK)
        {
            if (displayOn)
            {
                fmDisplay.clear();
                digitalWrite(LED_BUILTIN, LOW);
            }
            else
            {
                fmDisplay.display_show_dot(false);
                fmDisplay.display_int(display_measurement_number, measurement_units == MEASUREMENT_UNITS::DBM);
                digitalWrite(LED_BUILTIN, HIGH);
            }
            displayOn = !displayOn;
        }
        else if (measurement_mode == MEASUREMENT_MODE::CONTINIOUS)
        {
            fmDisplay.display_int(display_measurement_number, measurement_units == MEASUREMENT_UNITS::DBM);
        }
    }
    else if (state == STATE::FREQUENCY_SELECT)
    {
        display_frequency_band();
    }
    else if (state == STATE::MEASUREMENT_MODE_SELECT)
    {
        if (measurement_mode == MEASUREMENT_MODE::HOLD_PEAK)
        {
            fmDisplay.display_symbols(TEXT_HOLD);
        }
        else if (measurement_mode == MEASUREMENT_MODE::CONTINIOUS)
        {
            fmDisplay.display_symbols(TEXT_CONT);
        }
    }
}

void handle_ok_button_click()
{
    Serial.println("handle_ok_button_click");
    button_press_time = millis();
    turnoff_countdown = false;
    if (state == STATE::MAIN)
    {
        display_zeroing_animation();
        rf_power_dbm = 0;
        rf_power_mw = 0;
        rf_adc_value = 0;
        old_rf_adc_value = 0;
    }

    if (state == STATE::MEASUREMENT_MODE_SELECT)
    {
        state = STATE::MAIN;
    }
    else if (state == STATE::FREQUENCY_SELECT)
    {
        fmDisplay.display_show_dot(false);
        state = STATE::MAIN;
        display_save_animation();
        EEPROM.write(0, frequency_band);
    }
}

void handle_menu_button_click()
{
    Serial.println("handle_menu_button_click");
    button_press_time = millis();
    turnoff_countdown = false;

    int symbols[4];
    int text_to_scroll[20];
    if (state == STATE::MAIN)
    {
        Timer1.detachInterrupt();
        if (measurement_units == MEASUREMENT_UNITS::W)
        {
            measurement_units = MEASUREMENT_UNITS::DBM;
            int_to_symbols(display_measurement_number, symbols, false);
            memcpy(text_to_scroll, symbols, sizeof(symbols));
            memcpy(text_to_scroll + 4, TEXT_BLANK, sizeof(TEXT_BLANK));
            memcpy(text_to_scroll + 8, TEXT_DBM, sizeof(TEXT_DBM));
            memcpy(text_to_scroll + 12, TEXT_BLANK, sizeof(TEXT_BLANK));
            int_to_symbols(round(rf_power_dbm), symbols);
            memcpy(text_to_scroll + 16, symbols, sizeof(symbols));
            display_scroll_animation(text_to_scroll, sizeof(text_to_scroll) / sizeof(text_to_scroll[0]));
            delay(500);
            display_measurement_number = round(rf_power_dbm);
        }
        else if (measurement_units == MEASUREMENT_UNITS::DBM)
        {
            measurement_units = MEASUREMENT_UNITS::W;

            int_to_symbols(display_measurement_number, symbols, true);
            memcpy(text_to_scroll, symbols, sizeof(symbols));
            memcpy(text_to_scroll + 4, TEXT_BLANK, sizeof(TEXT_BLANK));
            memcpy(text_to_scroll + 8, TEXT_PO, sizeof(TEXT_PO));
            memcpy(text_to_scroll + 12, TEXT_BLANK, sizeof(TEXT_BLANK));
            int_to_symbols(round(rf_power_mw), symbols);
            memcpy(text_to_scroll + 16, symbols, sizeof(symbols));
            display_scroll_animation(text_to_scroll, sizeof(text_to_scroll) / sizeof(text_to_scroll[0]));
            delay(500);
            display_measurement_number = round(rf_power_mw);
        }
        Timer1.attachInterrupt(render_display);
    }
    else if (state == STATE::MEASUREMENT_MODE_SELECT)
    {
        if (measurement_mode == MEASUREMENT_MODE::HOLD_PEAK)
        {
            measurement_mode = MEASUREMENT_MODE::CONTINIOUS;
        }
        else if (measurement_mode == MEASUREMENT_MODE::CONTINIOUS)
        {
            measurement_mode = MEASUREMENT_MODE::HOLD_PEAK;
        }
    }
    else if (state == STATE::FREQUENCY_SELECT)
    {
        frequency_band++;
        if (frequency_band >= sizeof(available_frequency_bands) / sizeof(available_frequency_bands[0]))
        {
            frequency_band = 0;
        }
        display_frequency_band();
    }
}

void handle_menu_button_doubleclick()
{
    Serial.println("handle_menu_button_doubleclick");
    button_press_time = millis();
    turnoff_countdown = false;

    int symbols[4];
    int text_to_scroll[12];

    if (state == STATE::MAIN)
    {
        Timer1.detachInterrupt();
        state = STATE::MEASUREMENT_MODE_SELECT;

        int_to_symbols(display_measurement_number, symbols);
        memcpy(text_to_scroll, symbols, sizeof(symbols));
        memcpy(text_to_scroll + 4, TEXT_BLANK, sizeof(TEXT_BLANK));

        if (measurement_mode == MEASUREMENT_MODE::HOLD_PEAK)
        {
            memcpy(text_to_scroll + 8, TEXT_HOLD, sizeof(TEXT_HOLD));
        }
        else if (measurement_mode == MEASUREMENT_MODE::CONTINIOUS)
        {
            memcpy(text_to_scroll + 8, TEXT_CONT, sizeof(TEXT_CONT));
        }
        display_scroll_animation(text_to_scroll, sizeof(text_to_scroll) / sizeof(text_to_scroll[0]));

        Timer1.attachInterrupt(render_display);
    }
}

void handle_menu_button_longpress()
{
    Serial.println("handle_menu_button_longpress");
    button_press_time = millis();
    turnoff_countdown = false;

    int symbols[4];
    int text_to_scroll[20];

    if (state == STATE::MAIN)
    {
        Timer1.detachInterrupt();
        state = STATE::FREQUENCY_SELECT;

        int_to_symbols(display_measurement_number, symbols);
        memcpy(text_to_scroll, symbols, sizeof(symbols));
        memcpy(text_to_scroll + 4, TEXT_BLANK, sizeof(TEXT_BLANK));
        memcpy(text_to_scroll + 8, TEXT_FREQUENCY, sizeof(TEXT_FREQUENCY));
        memcpy(text_to_scroll + 12, TEXT_BLANK, sizeof(TEXT_BLANK));
        int_to_symbols(available_frequency_bands[frequency_band], symbols, true);
        memcpy(text_to_scroll + 16, symbols, sizeof(symbols));
        display_scroll_animation(text_to_scroll, sizeof(text_to_scroll) / sizeof(text_to_scroll[0]));

        Timer1.attachInterrupt(render_display);
    }
}

void handle_ok_button_longpress()
{
    Serial.println("handle_ok_button_longpress");
    shutdown_tone();
    // shut down
    digitalWrite(POWER_LATCH_PIN, LOW);
}

void setup()
{
    // Launch the power supply
    pinMode(POWER_LATCH_PIN, OUTPUT);
    digitalWrite(POWER_LATCH_PIN, HIGH);

    pinMode(BUTTON_MENU_PIN, INPUT_PULLUP);
    pinMode(BUTTON_OK_PIN, INPUT_PULLUP);
    pinMode(BUZZER_PIN, OUTPUT);
    pinMode(BATTERY_PIN, INPUT);
    pinMode(RF_PEAK_PIN, INPUT);

    analogReference(EXTERNAL);

    pinMode(LED_BUILTIN, OUTPUT);
    Serial.begin(57600);
    fmDisplay.start();
    fmDisplay.clear();

    startup_tone();
    display_battery_voltage();
    delay(1000);

    // Read frequency_band from EEPROM
    frequency_band = EEPROM.read(0);
    if (frequency_band >= sizeof(available_frequency_bands) / sizeof(available_frequency_bands[0]))
    {
        frequency_band = 1; // Default to 7.2MHz if the value is out of range
        EEPROM.write(0, frequency_band);
    }
    display_frequency_band();
    delay(1000);

    fmDisplay.display_show_dot(false);

    button_OK.setLongPressIntervalMs(2000);
    button_OK.attachPress(button_press_tone);
    button_OK.attachClick(handle_ok_button_click);
    button_OK.attachLongPressStart(handle_ok_button_longpress);

    button_MENU.setLongPressIntervalMs(2000);
    button_MENU.attachPress(button_press_tone);
    button_MENU.attachClick(handle_menu_button_click);
    button_MENU.attachDoubleClick(handle_menu_button_doubleclick);
    button_MENU.attachLongPressStart(handle_menu_button_longpress);

    Timer1.initialize(400000);              // Initialize timer to 500ms
    Timer1.attachInterrupt(render_display); // Attach the interrupt service routine
}

void loop()
{
    read_rf_power();
    button_OK.tick();
    button_MENU.tick();

    if (!turnoff_countdown && (millis() - button_press_time) > COUNTDOWN_DELAY)
    {
        Serial.println("Shutdown count down");
        tone(BUZZER_PIN, 2000, 300);
        delay(500);
        tone(BUZZER_PIN, 2000, 300);
        delay(500);
        tone(BUZZER_PIN, 2000, 300);
        delay(500);
        turnoff_countdown = true;
    }

    if (turnoff_countdown && (millis() - button_press_time) > SHUTDOWN_DELAY)
    {
        Serial.println("Shutting down after inactivity");
        shutdown_tone();
        // shut down
        digitalWrite(POWER_LATCH_PIN, LOW);
        delay(1000);
    }

    delay(10);
}

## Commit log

2024-12-30 feat: Initial commit
    [main.kicad_pcb, main.kicad_sch, main.sch]
2024-12-31 Add 3d model for enclosure
    [Box-top.stl, Ultimate_Box.scad]
2025-01-03 docs: clean up schematic and export to pdf and images
    [main.kicad_pcb, main.kicad_sch]
